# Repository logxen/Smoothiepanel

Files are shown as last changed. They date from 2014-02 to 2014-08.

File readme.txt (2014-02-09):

SmoothiePanel is an Open Source Hardware control interface for industrial robotic machinery. It adds a screen and user interface to allow easy control of a Smoothieboard. The current design brings a graphic LCD with RGB Backlight and changeable interface panel down to a port, optionally SPI, UART, or USB.

It is intended to control a Smoothieboard (http://smoothieware.org/), though could easily be connected to almost any logic control system. The firmware found in the firmware directory makes Smoothiepanel behave as a simple slave device that can be used via SPI, UART, or USB. As it is completely open source, however, it is very easy to write custom firmware that takes more advantage of its powerful 50MHz processor and 16 bits worth of extra gpio.

The latest version, Prototype 3, is based around the NXP LPC11UxxFBD64, which sports a 50MHz ARM Cortex-M0 processor with built in USB and up to 128KB of flash.

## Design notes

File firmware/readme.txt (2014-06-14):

Smoothiepanel is designed to function as a simple slave device. It can be used over USB, uart, and spi. USB and uart comms work the same, but spi is a bit different. The command list itself does not change between the three and can be found here: https://gist.github.com/logxen/8792351

USB and uart are set up for easy use from a keyboard. Each transaction consists of a command byte, represented by a decimal number from 0 to 255, followed by a space and a data byte, also represented by a decimal number from 0 to 255, followed by a '\n'. The panel will respond with a line containing two response bytes in hex format.

SPI uses the same two byte transactions. Drop the CS pin, send the command byte while receiving the previous command's first response byte, send the data byte while receiving the previous command's second response byte, then raise the CS pin. The CS pin must be raised between each 16-bit transaction to allow the panel to process the command.

To set up a build environment:

Clone https://github.com/arthurwolf/Smoothie and run the install script appropriate to your OS.

This will create a BuildShell script that you will run any time you want to use your GCC_ARM build environment.

Clone https://github.com/mbedmicro/mbed and get any basic dependencies that requires like Python installed.

Be sure to have run the BuildShell script, then from your mbed directory run: python workspace_tools/build.py -m LPC11U35_401 -t GCC_ARM -u

Finally, you need to add a section to your mbed/workspace_tools/tests.py like the following, but make sure to change "/path/to/git" to match wherever you cloned Smoothiepanel (for me that's "/home/logxen/git"):

    {
        "id": "Smoothiepanel", "description": "Smoothiepanel http://smoothieware.org/smoothiepanel",
        "source_dir": join("/path/to/git", "Smoothiepanel", "firmware"),
        "dependencies": [MBED_LIBRARIES, USB_LIBRARIES],
    },

To build:

Be sure to have run the BuildShell script, then from your mbed directory run: python workspace_tools/make.py -m LPC11U35_401 -t GCC_ARM -n Smoothiepanel

To flash:

If you are running Windows you can use the usb drag and drop system built into the mcu (plug in usb or reset while holding the isp button). Otherwise, for now, follow the process for flashing the Smoothie bootloader here using an FTDI without USB plugged in: http://smoothieware.org/flashing-the-bootloader

Eventually, I plan to have a bootloader with similar functionality to the one Triffid_Hunter wrote for Smoothie.

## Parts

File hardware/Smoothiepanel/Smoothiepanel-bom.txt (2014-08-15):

Partlist exported from C:/Users/Logxen/Documents/eagle/Smoothie/Smoothiepanel/Smoothiepanel/Smoothiepanel-Proto5.sch at 7/15/2014 9:03:24 AM

Qty Value         Device              Package            Parts                                                   Description                                                                                                                                                                                               MF MPN OC_FARNELL OC_NEWARK PROD_ID    VALUE
13  0.1uF         CAP0603-CAP         0603-CAP           C2, C3, C4, C5, C6, C7, C8, C9, C10, C12, C13, C16, C17 Capacitor                                                                                                                                                                                                                                             
6   0R            RESISTOR0603-RES    0603-RES           R6, R10, R11, R18, R20, R21                             Resistor                                                                                                                                                                                                                                              
1   1.5K          RESISTOR0603-RES    0603-RES           R23                                                     Resistor                                                                                                                                                                                                                                              
1   100R          RESISTOR0603-RES    0603-RES           R22                                                     Resistor                                                                                                                                                                                                                                              
8   10K           RESISTOR0603-RES    0603-RES           R2, R3, R4, R7, R8, R9, R13, R14                        Resistor                                                                                                                                                                                                                                              
1   10uF          CAP_POL1206         EIA3216            C11                                                     Capacitor Polarized                                                                                                                                                                                                                                   
1   12MHz         CRYSTALTHIN         CRYSTAL_3.2X2.5    Y1                                                      Crystals                                                                                                                                                                                                                                              
4   18pF          CAP0603-CAP         0603-CAP           C14, C15, C18, C19                                      Capacitor                                                                                                                                                                                                                                             
1   1uF           C-USC0805           C0805              C1                                                      CAPACITOR, American symbol                                                                                                                                                                                                                            
1   24K           RESISTOR0603-RES    0603-RES           R17                                                     Resistor                                                                                                                                                                                                                                              
2   330R          RESISTOR0603-RES    0603-RES           R1, R5                                                  Resistor                                                                                                                                                                                                                                              
2   33R           RESISTOR_0603MP     _0603MP            R16, R19                                                Resistors                                                                                                                                                                                                                                             
1   3K            RESISTOR0603-RES    0603-RES           R15                                                     Resistor                                                                                                                                                                                                                                              
1   BC857B        TRANSISTOR_PNPSMD   SOT23-3            Q1                                                      Generic PNP BJT. Double check pinouts against datasheets- not all devices are the same!                                                                                                                                                               
1   FB            INDUCTOR0603        0603               L1                                                      Inductors                                                                                                                                                                                                                                             
1   LM1117-3.3V   V_REG_LM1117SOT223  SOT223             U1                                                      Voltage Regulator LM1117                                                                                                                                                                                                                              
1   LPC176xFBD100 LPC1768             LQFP100            U2                                                      LPC1768 100 MHz 32-bit ARM Cortex-M3 based microcontroller featuring a high level of integration and low power consumption. 512 kB Flash, 64 kB SRAM, USB Device/Host/OTG, Ethernet, CAN, I2S, 10-bit DAC                                             
2   MBRA210LT3    DIODESMA            SMADIODE           D1, D2                                                  Diode                                                                                                                                                                                                                                                 
1   MCP4725       DAC_MCP4725         SOT23-6            U3                                                      MCP4725 - 12-Bit I2C DAC with on-board EEPROM                                                                                                                                                                                                         
1   POWER         LED0603             LED-0603           LED1                                                    LEDs                                                                                                                                                                                                                                                  
1   STATUS        LED0603             LED-0603           LED2                                                    LEDs                                                                                                                                                                                                                                                  

1   BOOT          TAC_SWITCHSMD       TACTILE_SWITCH_SMD S3                                                      Momentary Switch                                                                                                                                                                                                                                      
1   ISP           TAC_SWITCHSMD       TACTILE_SWITCH_SMD S2                                                      Momentary Switch                                                                                                                                                                                                                                      
1   JTAG          JTAG-CORTEXM3       2X05_1.27MM_SMT    JTAG1                                                   Serial Wire (SW-DP) Connector                                                                                                                                                                                                                         
1   RESET         TAC_SWITCHSMD       TACTILE_SWITCH_SMD S1                                                      Momentary Switch                                                                                                                                                                                                                                      
1   SD            SD_CARD_SOCKET4UCON SDCARD_4UCONN      X4                                                      SD Memory Card Connector, push-push normal type, CD enable, WP enable                                                                                                                                                                                 
1   SPI0          M03X2               2X3-SHROUDED       JP5                                                     Shrouded 2x3 .1" header, with keying.                                                                                                                                                                                                                 
1   USB-B         USBPTH              USB-B-PTH          X1                                                      USB Connectors                                                                                                                                                                                                                        CONN-08278 USB-B
1   VIN           180-2               180-2              Z1                                                      WEIDMUELLER CLAMP CONNECTOR                                                                                                                                                                                      unknown    unknown

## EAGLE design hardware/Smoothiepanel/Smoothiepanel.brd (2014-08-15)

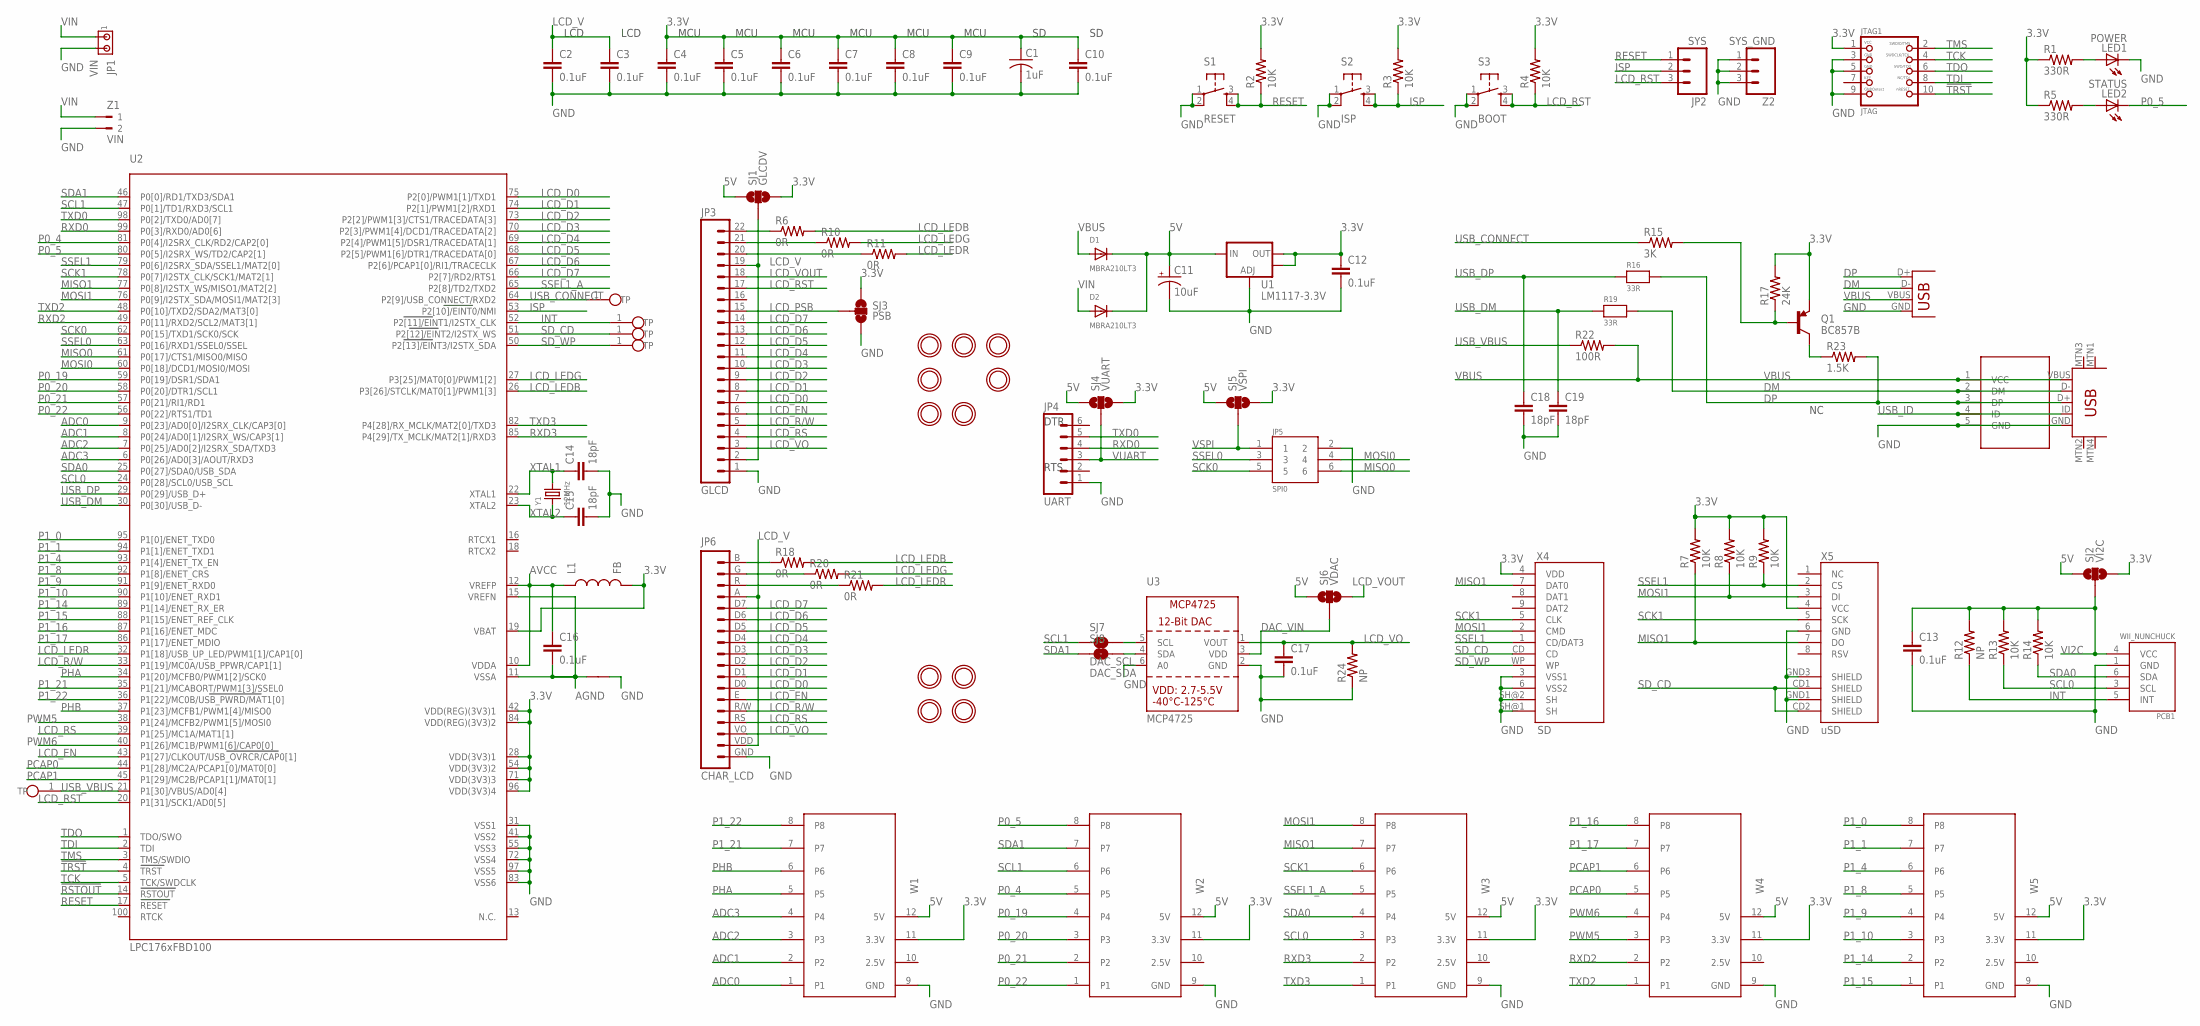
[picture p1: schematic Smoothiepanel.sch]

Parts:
C1: 1uF; C0805
C2, C3, C4, C5, C6, C7, C8, C9, C10, C12, C13, C16, C17: 0.1uF; 0603-CAP
C11: 10uF; EIA3216
C14, C15, C18, C19: 18pF; 0603-CAP
D1, D2: MBRA210LT3; SMADIODE
JP1: VIN; 10X02MTA
JP2: SYS; 1X03
JP3: GLCD; 1X22
JP4: UART; 1X06
JP5: SPI0; 2X3-SHROUDED
JP6: CHAR_LCD; TEXT_LCD
JTAG1: JTAG; 2X05_1.27MM_SMT
L1: FB; 0603
LED1: POWER; LED-0603
LED2: STATUS; LED-0603
MH1, MH2, MH3, MH4, MH5, MH6, MH7: MOUNTINGHOLE2.5_THICK; MOUNTINGHOLE_2.5_PLATED_THICK
MH8, MH9, MH10, MH11: MOUNTINGHOLE3.0THIN; MOUNTINGHOLE_3.0_PLATEDTHIN
N1: NET_LINK
PCB1: WII_NUNCHUCK
Q1: BC857B; SOT23-3
R1, R5: 330R; 0603-RES
R2, R3, R4, R7, R8, R9, R13, R14: 10K; 0603-RES
R6, R10, R11, R18, R20, R21: 0R; 0603-RES
R12, R24: NP; 0603-RES
R15: 3K; 0603-RES
R16, R19: 33R; _0603MP
R17: 24K; 0603-RES
R22: 100R; 0603-RES
R23: 1.5K; 0603-RES
S1: RESET; TACTILE_SWITCH_SMD
S2: ISP; TACTILE_SWITCH_SMD
S3: BOOT; TACTILE_SWITCH_SMD
SJ1: GLCDV; SJ_3
SJ2: VI2C; SJ_3
SJ3: PSB; SJ_3
SJ4: VUART; SJ_3
SJ5: VSPI; SJ_3
SJ6: VDAC; SJ_3
SJ7: DAC_SCL; SJ_2S-TRACE
SJ8: DAC_SDA; SJ_2S-TRACE
TP1, TP3, TP4, TP5, TP6: TPAD1.5; TPAD-1.5
U1: LM1117-3.3V; SOT223
U2: LPC176xFBD100; LQFP100
U3: MCP4725; SOT23-6
W1: WING1; PAPILIO-WING-8BITS-F
W2: WING2; PAPILIO-WING-8BITS-F
W3: WING3; PAPILIO-WING-8BITS-F
W4: WING4; PAPILIO-WING-8BITS-F
W5: WING5; PAPILIO-WING-8BITS-F
X1: USB-B; USB-B-PTH
X2: mUSB; USB-MINIB
X3: USB-MICROB-SMDRECEPT; USB-MICROB-RECEPT
X4: SD; SDCARD_4UCONN
X5: uSD; MICRO-SD-SOCKET-PP
Y1: 12MHz; CRYSTAL_3.2X2.5
Z1: VIN; 180-2
Z2: SYS_GND; 1X03

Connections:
3.3V: C1.1, C4.1, C5.1, C6.1, C7.1, C8.1, C9.1, C10.1, C12.1, JTAG1.1, L1.2, Q1.2 (E), R1.1, R2.2, R3.2, R4.2, R5.1, R7.2, R8.2, R9.2, R17.2, SJ1.3, SJ2.3, SJ3.1, SJ4.3, SJ5.3, U1.2 (OUT), U1.4 (OUT), U2.19 (VBAT), U2.28 (VDD(3V3)1), U2.42 (VDD(REG)(3V3)1), U2.54 (VDD(3V3)2), U2.71 (VDD(3V3)3), U2.84 (VDD(REG)(3V3)2), U2.96 (VDD(3V3)4), W1.11 (3.3V), W2.11 (3.3V), W3.11 (3.3V), W4.11 (3.3V), W5.11 (3.3V), X4.4 (VDD), X5.4 (VCC)
5V: C11.A (+), D1.C, D2.C, SJ1.1, SJ2.1, SJ4.1, SJ5.1, SJ6.1, U1.3 (IN), W1.12 (5V), W2.12 (5V), W3.12 (5V), W4.12 (5V), W5.12 (5V)
!RSTOUT!: U2.14 (RSTOUT)
!TRST!: JTAG1.10, U2.4 (TRST)
ADC0: U2.9 (P0[23]/AD0[0]/I2SRX_CLK/CAP3[0]), W1.1
ADC1: U2.8 (P0[24]/AD0[1]/I2SRX_WS/CAP3[1]), W1.2
ADC2: U2.7 (P0[25]/AD0[2]/I2SRX_SDA/TXD3), W1.3
ADC3: U2.6 (P0[26]/AD0[3]/AOUT/RXD3), W1.4
AGND: C16.2, N1.P$1, U2.11 (VSSA), U2.15 (VREFN)
AVCC: C16.1, L1.1, U2.10 (VDDA), U2.12 (VREFP)
DAC_SCL_RES: SJ7.2, U3.5 (SCL)
DAC_SDA_RES: SJ8.2, U3.4 (SDA)
DAC_VIN: SJ6.2, U3.3 (VDD)
DM: R19.2, X1.D-, X2.D-, X3.2 (DM)
DP: R16.2, R23.2, X1.D+, X2.D+, X3.3 (DP)
GND: C1.2, C2.2, C3.2, C4.2, C5.2, C6.2, C7.2, C8.2, C9.2, C10.2, C11.C (-), C12.2, C13.2, C14.2, C15.2, C17.2, C18.2, C19.2, JP1.2, JP3.1, JP4.1, JP5.2, JP6.GND (1), JTAG1.3, JTAG1.5, JTAG1.9, LED1.C, N1.P$2, PCB1.1 (GND), R24.1, S1.1, S1.2, S2.1, S2.2, S3.1, S3.2, SJ3.3, U1.1 (ADJ), U2.31 (VSS1), U2.41 (VSS2), U2.55 (VSS3), U2.72 (VSS4), U2.83 (VSS6), U2.97 (VSS5), U3.2 (GND), U3.6 (A0), W1.9 (GND), W2.9 (GND), W3.9 (GND), W4.9 (GND), W5.9 (GND), X1.GND, X2.GND, X3.5 (GND), X4.3 (VSS1), X4.6 (VSS2), X4.SH@1 (SH), X4.SH@2 (SH), X5.6 (GND), X5.GND1 (SHIELD), X5.GND3 (SHIELD), Z1.2, Z2.1, Z2.2, Z2.3
INT: PCB1.5 (INT), R12.1, TP4.1, U2.52 (P2[11]/EINT1/I2STX_CLK)
ISP: JP2.2, R3.1, S2.3, S2.4, U2.53 (P2[10]/EINT0/NMI)
LCD_D0: JP3.7, JP6.D0 (7), U2.75 (P2[0]/PWM1[1]/TXD1)
LCD_D1: JP3.8, JP6.D1 (8), U2.74 (P2[1]/PWM1[2]/RXD1)
LCD_D2: JP3.9, JP6.D2 (9), U2.73 (P2[2]/PWM1[3]/CTS1/TRACEDATA[3])
LCD_D3: JP3.10, JP6.D3 (10), U2.70 (P2[3]/PWM1[4]/DCD1/TRACEDATA[2])
LCD_D4: JP3.11, JP6.D4 (11), U2.69 (P2[4]/PWM1[5]/DSR1/TRACEDATA[1])
LCD_D5: JP3.12, JP6.D5 (12), U2.68 (P2[5]/PWM1[6]/DTR1/TRACEDATA[0])
LCD_D6: JP3.13, JP6.D6 (13), U2.67 (P2[6]/PCAP1[0]/RI1/TRACECLK)
LCD_D7: JP3.14, JP6.D7 (14), U2.66 (P2[7]/RD2/RTS1)
LCD_EN: JP3.6, JP6.E (6), U2.43 (P1[27]/CLKOUT/USB_OVRCR/CAP0[1])
LCD_LEDB: R6.2, R18.2, U2.26 (P3[26]/STCLK/MAT0[1]/PWM1[3])
LCD_LEDB_RES: JP3.22, R6.1
LCD_LEDB_RES1: JP6.B (18), R18.1
LCD_LEDG: R10.2, R20.2, U2.27 (P3[25]/MAT0[0]/PWM1[2])
LCD_LEDG_RES: JP3.21, R10.1
LCD_LEDG_RES1: JP6.G (17), R20.1
LCD_LEDR: R11.2, R21.2, U2.32 (P1[18]/USB_UP_LED/PWM1[1]/CAP1[0])
LCD_LEDR_RES: JP3.20, R11.1
LCD_LEDR_RES1: JP6.R (16), R21.1
LCD_PSB: JP3.15, SJ3.2
LCD_R/W: JP3.5, JP6.R/W (5), U2.33 (P1[19]/MC0A/USB_PPWR/CAP1[1])
LCD_RS: JP3.4, JP6.RS (4), U2.39 (P1[25]/MC1A/MAT1[1])
LCD_RST: JP2.3, JP3.17, R4.1, S3.3, S3.4, U2.20 (P1[31]/SCK1/AD0[5])
LCD_V: C2.1, C3.1, JP3.2, JP3.19, JP6.A (15), JP6.VDD (2), SJ1.2
LCD_VO: C17.1, JP3.3, JP6.VO (3), R24.2, U3.1 (VOUT)
LCD_VOUT: JP3.18, SJ6.3
LED1_R: LED1.A, R1.2
LED2_R: LED2.A, R5.2
MISO0: JP5.6, U2.61 (P0[17]/CTS1/MISO0/MISO)
MISO1: R7.1, U2.77 (P0[8]/I2STX_WS/MISO1/MAT2[2]), W3.7, X4.7 (DAT0), X5.7 (DO)
MOSI0: JP5.4, U2.60 (P0[18]/DCD1/MOSI0/MOSI)
MOSI1: R8.1, U2.76 (P0[9]/I2STX_SDA/MOSI1/MAT2[3]), W3.8, X4.2 (CMD), X5.3 (DI)
P0_4: U2.81 (P0[4]/I2SRX_CLK/RD2/CAP2[0]), W2.5
P0_5: LED2.C, U2.80 (P0[5]/I2SRX_WS/TD2/CAP2[1]), W2.8
P0_19: U2.59 (P0[19]/DSR1/SDA1), W2.4
P0_20: U2.58 (P0[20]/DTR1/SCL1), W2.3
P0_21: U2.57 (P0[21]/RI1/RD1), W2.2
P0_22: U2.56 (P0[22]/RTS1/TD1), W2.1
P1_0: U2.95 (P1[0]/ENET_TXD0), W5.8
P1_1: U2.94 (P1[1]/ENET_TXD1), W5.7
P1_4: U2.93 (P1[4]/ENET_TX_EN), W5.6
P1_8: U2.92 (P1[8]/ENET_CRS), W5.5
P1_9: U2.91 (P1[9]/ENET_RXD0), W5.4
P1_10: U2.90 (P1[10]/ENET_RXD1), W5.3
P1_14: U2.89 (P1[14]/ENET_RX_ER), W5.2
P1_15: U2.88 (P1[15]/ENET_REF_CLK), W5.1
P1_16: U2.87 (P1[16]/ENET_MDC), W4.8
P1_17: U2.86 (P1[17]/ENET_MDIO), W4.7
P1_21: U2.35 (P1[21]/MCABORT/PWM1[3]/SSEL0), W1.7
P1_22: U2.36 (P1[22]/MC0B/USB_PWRD/MAT1[0]), W1.8
PCAP0: U2.44 (P1[28]/MC2A/PCAP1[0]/MAT0[0]), W4.5
PCAP1: U2.45 (P1[29]/MC2B/PCAP1[1]/MAT0[1]), W4.6
PHA: U2.34 (P1[20]/MCFB0/PWM1[2]/SCK0), W1.5
PHB: U2.37 (P1[23]/MCFB1/PWM1[4]/MISO0), W1.6
PWM5: U2.38 (P1[24]/MCFB2/PWM1[5]/MOSI0), W4.3
PWM6: U2.40 (P1[26]/MC1B/PWM1[6]/CAP0[0]), W4.4
RESET: JP2.1, R2.1, S1.3, S1.4, U2.17 (RESET)
RXD0: JP4.4, U2.99 (P0[3]/RXD0/AD0[6])
RXD2: U2.49 (P0[11]/RXD2/SCL2/MAT3[1]), W4.2
RXD3: U2.85 (P4[29]/TX_MCLK/MAT2[1]/RXD3), W3.2
SCK0: JP5.5, U2.62 (P0[15]/TXD1/SCK0/SCK)
SCK1: U2.78 (P0[7]/I2STX_CLK/SCK1/MAT2[1]), W3.6, X4.5 (CLK), X5.5 (SCK)
SCL0: PCB1.3 (SCL), R13.1, U2.24 (P0[28]/SCL0/USB_SCL), W3.3
SCL1: SJ7.1, U2.47 (P0[1]/TD1/RXD3/SCL1), W2.6
SDA0: PCB1.6 (SDA), R14.1, U2.25 (P0[27]/SDA0/USB_SDA), W3.4
SDA1: SJ8.1, U2.46 (P0[0]/RD1/TXD3/SDA1), W2.7
SD_CD: TP5.1, U2.51 (P2[12]/EINT2/I2STX_WS), X4.CD, X5.CD1 (SHIELD), X5.CD2 (SHIELD)
SD_WP: TP6.1, U2.50 (P2[13]/EINT3/I2STX_SDA), X4.WP
SSEL0: JP5.3, U2.63 (P0[16]/RXD1/SSEL0/SSEL)
SSEL1: R9.1, U2.79 (P0[6]/I2SRX_SDA/SSEL1/MAT2[0]), X4.1 (CD/DAT3), X5.2 (CS)
SSEL1_A: U2.65 (P2[8]/TD2/TXD2), W3.5
TCK: JTAG1.4, U2.5 (TCK/SWDCLK)
TDI: JTAG1.8, U2.2 (TDI)
TDO: JTAG1.6, U2.1 (TDO/SWO)
TMS: JTAG1.2, U2.3 (TMS/SWDIO)
TXD0: JP4.5, U2.98 (P0[2]/TXD0/AD0[7])
TXD2: U2.48 (P0[10]/TXD2/SDA2/MAT3[0]), W4.1
TXD3: U2.82 (P4[28]/RX_MCLK/MAT2[0]/TXD3), W3.1
USB_CONNECT: R15.1, TP3.1, U2.64 (P2[9]/USB_CONNECT/RXD2)
USB_CONNECT_BASE: Q1.1 (B), R15.2, R17.1
USB_CONNECT_COLLECTOR: Q1.3 (C), R23.1
USB_DM: C19.1, R19.1, U2.30 (P0[30]/USB_D-)
USB_DP: C18.1, R16.1, U2.29 (P0[29]/USB_D+)
USB_ID: X2.ID, X3.4 (ID)
USB_VBUS: R22.1, TP1.1, U2.21 (P1[30]/VBUS/AD0[4])
VBUS: D1.A, R22.2, X1.VBUS, X2.VBUS, X3.1 (VCC)
VI2C: C13.1, PCB1.4 (VCC), R12.2, R13.2, R14.2, SJ2.2
VIN: D2.A, JP1.1, Z1.1
VSPI: JP5.1, SJ5.2
VUART: JP4.3, SJ4.2
XTAL1: C14.1, U2.22 (XTAL1), Y1.2
XTAL2: C15.1, U2.23 (XTAL2), Y1.1

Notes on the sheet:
DTR
RTS
LCD
MCU

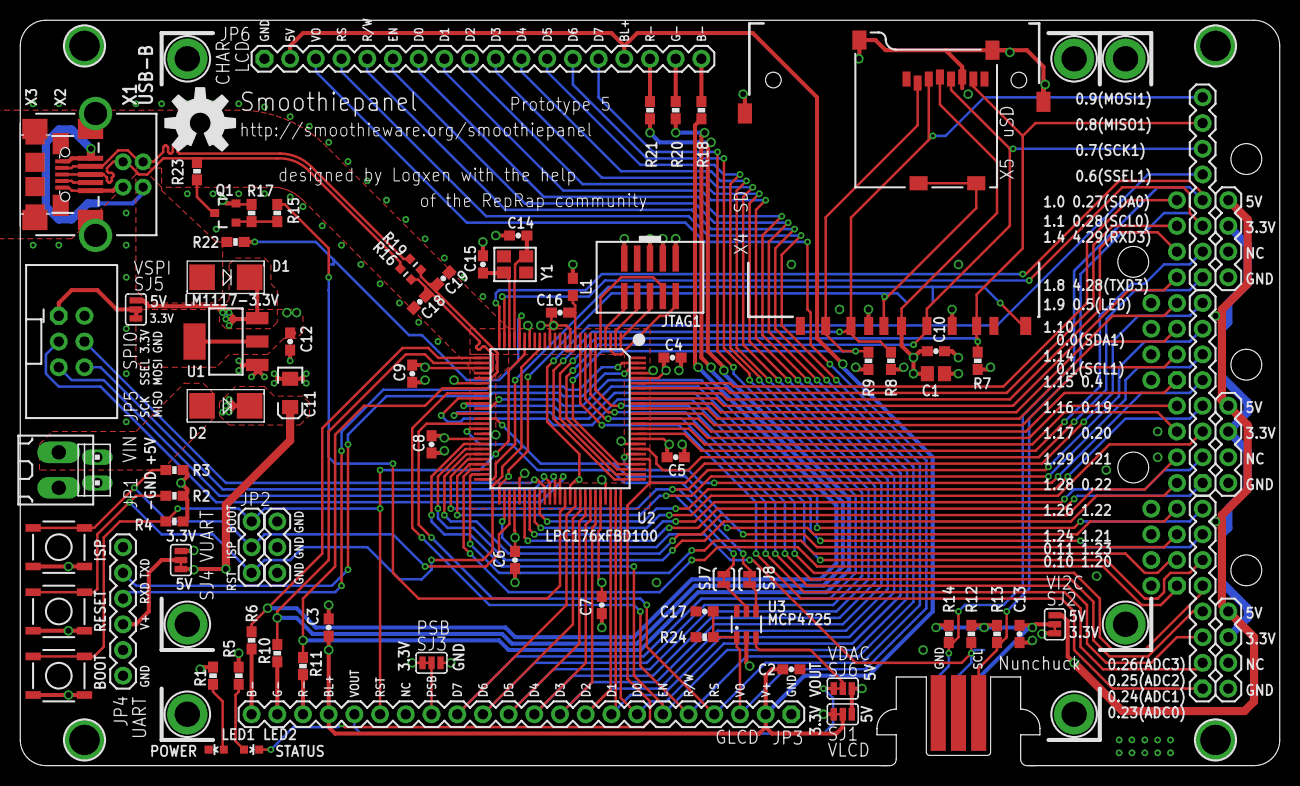
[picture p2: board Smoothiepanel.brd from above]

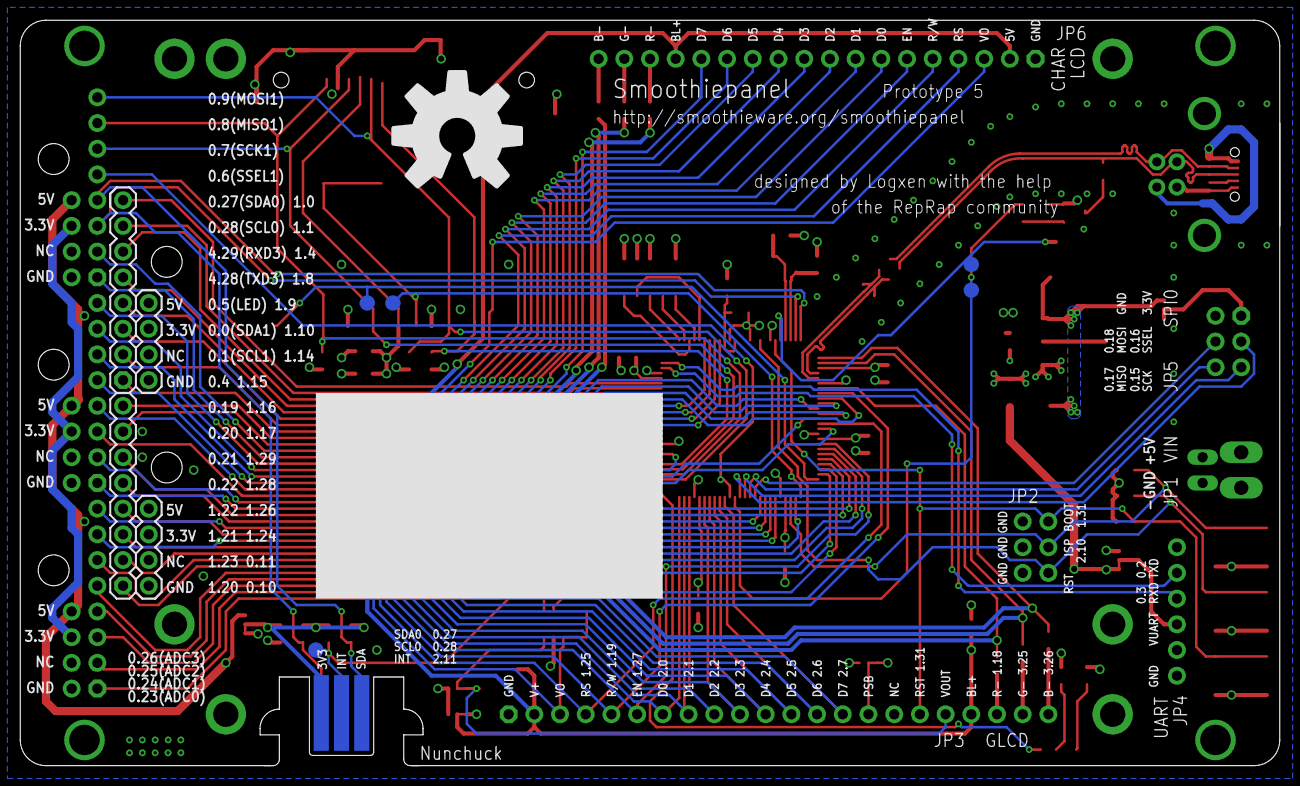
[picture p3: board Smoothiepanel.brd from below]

Board: 4 copper layers, 124.5 x 73.7 mm, 103 parts (8 on the bottom side), 108 nets.

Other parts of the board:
U$1: OSHW-LOGO-HUGE
U$2: OSHW-LOGO-L

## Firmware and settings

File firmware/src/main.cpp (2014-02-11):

#include "mbed.h"
#include "USBSerial.h"

#include "nunchuck.h"
#include "utils.h"

#define USB_VID         0x1D50
#define USB_PID         0x60A0
#define USB_REV         0x00
#define VERSION         0x0001

USBSerial usbdevice(USB_VID, USB_PID, USB_REV); // vid pid rev
Serial uart(P0_19, P0_18); // tx, rx
SPISlave spidevice(P0_9, P0_8, P0_10, P0_2); // mosi, miso, sck, ssel

BusInOut lcd_d(P1_0, P1_1, P1_2, P1_3, P1_4, P1_5, P1_6, P1_7);
DigitalOut lcd_rs(P0_17);
DigitalOut lcd_rw(P0_10);
DigitalOut lcd_en(P0_20);
DigitalOut lcd_psb(P1_28);
DigitalOut lcd_rst(P1_27);

SPI spimaster(P1_22, P1_21, P1_20); // mosi, miso, sck
DigitalOut spi_ssel(P1_23); // spi port ssel
DigitalOut sd_ssel(P0_7); // sd card ssel
DigitalIn sd_cd(P1_18); // sd card detect
DigitalIn sd_wp(P1_19); // sd card write protect

I2C i2c(P0_5, P0_4); // sda, scl

int nunchuck_rate;

bool encoder_running = false;
int16_t encoder_count = 0;
uint8_t encoder_a_pin;
uint8_t encoder_b_pin;
bool encoder_a_wing;
bool encoder_b_wing;

int processcommand(int c, int d) {
    int r;
    uint32_t t;
//    analogin_t adc;

    switch (c) {
        // System
        case 0x00: // nop
            r = 0x0000;
            break;

        case 0x01: // read usb vid
            r = USB_VID;
            break;
        case 0x02: // read usb pid
            r = USB_PID;
            break;
        case 0x03: // read usb revision
            r = USB_REV;
            break;
        case 0x04: // read version
            r = VERSION;
            break;

        // LCD
        case 0x10: // write lcd data byte
            lcd_d.output();
            lcd_d = d;
            lcd_rs = 1; // 0 cmd, 1 dat
            lcd_rw = 0; // 0 write, 1 read
            lcd_en = 0;
            wait(0.01);
            lcd_en = 1;
            wait(0.01);
            lcd_en = 0;
            r = 0x1000 + d;
            break;
        case 0x11: // read lcd data byte
            lcd_d.input();
            lcd_rs = 1; // 0 cmd, 1 dat
            lcd_rw = 1; // 0 write, 1 read
            lcd_en = 0;
            wait(0.01);
            lcd_en = 1;
            wait(0.01);
            r = 0x1100 + lcd_d;
            lcd_en = 0;
            break;
        case 0x12: // write lcd command byte
            lcd_d.output();
            lcd_d = d;
            lcd_rs = 0; // 0 cmd, 1 dat
            lcd_rw = 0; // 0 write, 1 read
            lcd_en = 0;
            wait(0.01);
            lcd_en = 1;
            wait(0.01);
            lcd_en = 0;
            r = 0x1200 + d;
            break;
        case 0x13: // read lcd command byte
            lcd_d.input();
            lcd_rs = 0; // 0 cmd, 1 dat
            lcd_rw = 1; // 0 write, 1 read
            lcd_en = 0;
            wait(0.01);
            lcd_en = 1;
            wait(0.01);
            r = 0x1300 + lcd_d;
            lcd_en = 0;
            break;
        case 0x14: // reset lcd
            lcd_rst = 1;
            wait(0.01);
            lcd_rst = 0;
            r = 0x1400 + d;
            break;

        // LCD Contrast
        case 0x18: // write lcd contrast dac
            r = 0x1800 + d;
            break;
        case 0x19: // read lcd contrast dac
            r = 0x1900 + d;
            break;

        // I2C
        case 0x20: // write i2c
            r = 0x2000 + i2c.write(d);
            break;
        case 0x21: // read i2c
            r = 0x2100 + i2c.read(d);
            break;
        case 0x22: // start i2c + address
            i2c.start();
            r = 0x2200 + i2c.write(d);
            break;
        case 0x23: // stop i2c
            i2c.stop();
            r = 0x2300;
            break;

        // SPI
        case 0x28: // write spi
            r = 0x2800 + spimaster.write(d);

        // Wing1
        case 0x40: // write wing1
            t = LPC_GPIO->PIN[0];
            t &= 0xFF3E07FF;
            t |= (d & 0x3F) << 11;
            t |= (d & 0xC0) << 16;
            LPC_GPIO->PIN[0] = t;
            r = 0x4000 + d;
            break;
        case 0x41: // read wing1
            t = LPC_GPIO->PIN[0];
            r = 0x4100 + ((t & 0x0001F800) >> 11) + ((t & 0x00C00000) >> 16);
            break;
        case 0x42: // set wing1
            LPC_GPIO->SET[0] = ((d & 0x3F) << 11) + ((d & 0xC0) << 16);
            r = 0x4200 + d;
            break;
        case 0x43: // clear wing1
            LPC_GPIO->CLR[0] = ((d & 0x3F) << 11) + ((d & 0xC0) << 16);
            r = 0x4300 + d;
            break;
        case 0x44: // not wing1
            LPC_GPIO->NOT[0] = ((d & 0x3F) << 11) + ((d & 0xC0) << 16);
            r = 0x4400 + d;
            break;
        case 0x45: // dir wing1
            t = LPC_GPIO->DIR[0];
            t &= 0xFF3E07FF;
            t |= (d & 0x3F) << 11;
            t |= (d & 0xC0) << 16;
            LPC_GPIO->DIR[0] = t;
            r = 0x4500 + d;
            break;
        case 0x46: // masked write wing1
            r = 0x4600 + d;
            break;
        case 0x47: // mask wing1
            r = 0x4700 + d;
            break;
        case 0x48: // configure wing1 bit0 P0_11
            r = write_iocon(P0_11, d);
            break;
        case 0x49: // configure wing1 bit1 P0_12
            r = write_iocon(P0_12, d);
            break;
        case 0x4A: // configure wing1 bit2 P0_13
            r = write_iocon(P0_13, d);
            break;
        case 0x4B: // configure wing1 bit3 P0_14
            r = write_iocon(P0_14, d);
            break;
        case 0x4C: // configure wing1 bit4 P0_15
            r = write_iocon(P0_15, d);
            break;
        case 0x4D: // configure wing1 bit5 P0_16
            r = write_iocon(P0_16, d);
            break;
        case 0x4E: // configure wing1 bit6 P0_22
            r = write_iocon(P0_22, d);
            break;
        case 0x4F: // configure wing1 bit7 P0_23
            r = write_iocon(P0_23, d);
            break;

        // Wing2
        case 0x50: // write wing2
            t = LPC_GPIO->PIN[1];
            t &= 0xFFFF00FF;
            t |= (d & 0xFF) << 8;
            LPC_GPIO->PIN[1] = t;
            r = 0x5000 + d;
            break;
        case 0x51: // read wing2
            r = 0x5100 + ((LPC_GPIO->PIN[1] & 0x0000FF00) >> 8);
            break;
        case 0x52: // set wing2
            LPC_GPIO->SET[1] = (d & 0xFF) << 8;
            r = 0x5200 + d;
            break;
        case 0x53: // clear wing2
            LPC_GPIO->CLR[1] = (d & 0xFF) << 8;
            r = 0x5300 + d;
            break;
        case 0x54: // not wing2
            LPC_GPIO->NOT[1] = (d & 0xFF) << 8;
            r = 0x5400 + d;
            break;
        case 0x55: // dir wing2
            t = LPC_GPIO->DIR[1];
            t &= 0xFFFF00FF;
            t |= (d & 0xFF) << 8;
            LPC_GPIO->DIR[1] = t;
            r = 0x5500 + d;
            break;
        case 0x56: // masked write wing2
            r = 0x5600 + d;
            break;
        case 0x57: // mask wing2
            r = 0x5700 + d;
            break;
        case 0x58: // configure wing2 bit0 P1_8
            r = write_iocon(P1_8, d);
            break;
        case 0x59: // configure wing2 bit1 P1_9
            r = write_iocon(P1_9, d);
            break;
        case 0x5A: // configure wing2 bit2 P1_10
            r = write_iocon(P1_10, d);
            break;
        case 0x5B: // configure wing2 bit3 P1_11
            r = write_iocon(P1_11, d);
            break;
        case 0x5C: // configure wing2 bit4 P1_12
            r = write_iocon(P1_12, d);
            break;
        case 0x5D: // configure wing2 bit5 P1_13
            r = write_iocon(P1_13, d);
            break;
        case 0x5E: // configure wing2 bit6 P1_14
            r = write_iocon(P1_14, d);
            break;
        case 0x5F: // configure wing2 bit7 P1_15
            r = write_iocon(P1_15, d);
            break;

        // Ext Pins
        case 0x60: // write ext
            LPC_GPIO->W0[1] = d & 0x80;
            LPC_GPIO->W0[7] = d & 0x10;
            LPC_GPIO->W0[21] = d & 0x40;
            LPC_GPIO->W1[23] = d & 0x20;
            t = LPC_GPIO->PIN[1];
            t &= 0xFFF0FFFF;
            t |= (d & 0x0F) << 16;
            LPC_GPIO->PIN[1] = t;
            r = 0x6000 + d;
            break;
        case 0x61: // read ext
            t = LPC_GPIO->B0[1] << 7;
            t |= LPC_GPIO->B0[7] << 4;
            t |= LPC_GPIO->B0[21] << 6;
            t |= LPC_GPIO->B1[23] << 5;
            t |= (LPC_GPIO->PIN[1] & 0x000F0000) >> 16;
            r = 0x6100 + t;
            break;
        case 0x62: // set ext
            t = (d & 0x80) >> 6;
            t |= (d & 0x10) << 3;
            t |= (d & 0x40) << 15;
            LPC_GPIO->SET[0] = t;
            t = (d & 0x0F) << 16;
            t |= (d & 0x20) << 18;
            LPC_GPIO->SET[1] = t;
            r = 0x6200 + d;
            break;
        case 0x63: // clear ext
            t = (d & 0x80) >> 6;
            t |= (d & 0x10) << 3;
            t |= (d & 0x40) << 15;
            LPC_GPIO->CLR[0] = t;
            t = (d & 0x0F) << 16;
            t |= (d & 0x20) << 18;
            LPC_GPIO->CLR[1] = t;
            r = 0x6300 + d;
            break;
        case 0x64: // not ext
            t = (d & 0x80) >> 6;
            t |= (d & 0x10) << 3;
            t |= (d & 0x40) << 15;
            LPC_GPIO->NOT[0] = t;
            t = (d & 0x0F) << 16;
            t |= (d & 0x20) << 18;
            LPC_GPIO->NOT[1] = t;
            r = 0x6400 + d;
            break;
        case 0x65: // dir ext
            t = LPC_GPIO->DIR[0] & 0xFFDFFF7D;
            t |= (d & 0x80) >> 6;
            t |= (d & 0x10) << 3;
            t |= (d & 0x40) << 15;
            LPC_GPIO->DIR[0] = t;
            t = LPC_GPIO->DIR[1] & 0xFF70FFFF;
            t |= (d & 0x0F) << 16;
            t |= (d & 0x20) << 18;
            LPC_GPIO->DIR[1] = t;
            r = 0x6500 + d;
            break;
        case 0x66: // masked write ext
            r = 0x6600 + d;
            break;
        case 0x67: // mask ext
            r = 0x6700 + d;
            break;
        case 0x6C: // configure ext bit4 P1_16 DAC_SDA
            r = write_iocon(P1_16, d);
            break;
        case 0x6D: // configure ext bit5 P1_17 DAC_SCL
            r = write_iocon(P1_17, d);
            break;
        case 0x69: // configure ext bit1 P1_18 SD_CD
            r = write_iocon(P1_18, d);
            break;
        case 0x6A: // configure ext bit2 P1_19 SD_WP
            r = write_iocon(P1_19, d);
            break;
        case 0x68: // configure ext bit0 P0_7  SD_SSEL
            r = write_iocon(P0_7, d);
            break;
        case 0x6B: // configure ext bit3 P1_23 SPI_SSEL
            r = write_iocon(P1_23, d);
            break;
        case 0x6E: // configure ext bit6 P0_21 I2C_INT
            r = write_iocon(P0_21, d);
            break;
        case 0x6F: // configure ext bit7 P0_1  ISP
            r = write_iocon(P0_1, d);
            break;

        // ADC (available on Wing1 pins by setting 0x48 - 0x4F bits 2:0 to 0x2)
        case 0x70: // sample + read adc0
            r = read_adc(P0_11);
            break;
        case 0x71: // sample + read adc0
            r = read_adc(P0_12);
            break;
        case 0x72: // sample + read adc0
            r = read_adc(P0_13);
            break;
        case 0x73: // sample + read adc0
            r = read_adc(P0_14);
            break;
        case 0x74: // sample + read adc0
            r = read_adc(P0_15);
            break;
        case 0x75: // sample + read adc0
            r = read_adc(P0_16);
            break;
        case 0x76: // sample + read adc0
            r = read_adc(P0_22);
            break;
        case 0x77: // sample + read adc0
            r = read_adc(P0_23);
            break;

        // PWM (available on pins: W2_5 W2_6 W2_7 W1_6 LCD_R LCD_G LCD_B)
        case 0x78: // write pwm control reg
            r = 0x7800 + pwm_init(d);
            break;
        case 0x79: // write pwm1 / W2_5 / P1_13
            r = 0x7900 + pwm_write(0, d);
            break;
        case 0x7A: // write pwm2 / W2_6 / P1_14
            r = 0x7A00 + pwm_write(1, d);
            break;
        case 0x7B: // write pwm3 / W2_7 / P1_15
            r = 0x7B00 + pwm_write(2, d);
            break;
        case 0x7C: // write pwm5 / W1_6 / P0_22
            r = 0x7C00 + pwm_write(3, d);
            break;
        case 0x7D: // write pwm6 / LCD_R / P1_24
            r = 0x7D00 + pwm_write(4, d);
            break;
        case 0x7E: // write pwm7 / LCD_G / P1_25
            r = 0x7E00 + pwm_write(5, d);
            break;
        case 0x7F: // write pwm8 / LCD_B / P1_26
            r = 0x7F00 + pwm_write(6, d);
            break;

        // other functions

        // nunchuck
        case 0x80: // init nunchuck (write 0 to sample manually, write >0 to set auto sampling speed)
            nunchuck_poll(&i2c);
            nunchuck_rate = (nunchuck_type >= 0) ? d : 0;
            r = nunchuck_type;
            break;
        case 0x81: // read nunchuck device type
            r = nunchuck_type;
            break;
        case 0x82: // read nunchuck byte 1 & 2
            r = (nunchuck_data[0] << 8) + nunchuck_data[1];
            break;
        case 0x83: // read nunchuck byte 3 & 4
            r = (nunchuck_data[2] << 8) + nunchuck_data[3];
            break;
        case 0x84: // read nunchuck byte 5 & 6
            r = (nunchuck_data[4] << 8) + nunchuck_data[5];
            break;
        case 0x85: // sample nunchuck
            r = 0x8500 + nunchuck_read(&i2c);
            break;

        // encoder
        case 0x86: // init encoder (data bits: 7 channel a wing, 6:4 channel a pin, 3 channel b wing, 2:0 channel b pin)
            r = 0x8600;
            encoder_a_wing = (d>>7)&0x01;
            encoder_a_pin = (d>>4)&0x07;
            encoder_b_wing = (d>>3)&0x01;
            encoder_b_pin = d&0x07;
            encoder_running = true;
            break;
        case 0x87: // read encoder (data: 1 to reset counter, 0 to not reset counter)
            r = encoder_count;
            if (d == 1) encoder_count = 0;
            break;

        // 0xDEAD
        default: // unrecognized command
            r = 0xDEAD;
            break;
    }
    return r;
}

char usb_buf[16];
int usb_pos = 0;
void usbdevice_onloop() {
    if(usbdevice.available()) {
        usb_buf[usb_pos] = usbdevice.getc();
        if (usb_buf[usb_pos] == '\n') {
            usb_buf[usb_pos] = '\0';
            usb_pos = 0;
            char * command = strtok(usb_buf, " \t\r\n");
            char * data = strtok(NULL, " \t\r\n");
            if(command != NULL && data != NULL) {
                int c = atoi(command);
                int d = atoi(data);
                int r = processcommand(c, d);
                usbdevice.printf("%d %d\r\n", c, d);
                usbdevice.printf("0x%x 0x%x\r\n", (r & 0xFF00) >> 8, r & 0x00FF);
            }
        }
        else if (usb_pos < 15) {
            usb_pos++;
        }
    }
}

char uart_buf[16];
int uart_pos = 0;
void uartdevice_onloop() {
    if(uart.readable()) {
        uart_buf[uart_pos] = uart.getc();
        if(uart_buf[uart_pos] == '\n') {
            uart_buf[uart_pos] = '\0';
            uart_pos = 0;
            char * command = strtok(uart_buf, " \t\r\n");
            char * data = strtok(NULL, " \t\r\n");
            if(command != NULL && data != NULL) {
                int c = atoi(command);
                int d = atoi(data);
                int r = processcommand(c, d);
                uart.printf("%d %d\r\n", c, d);
                uart.printf("0x%x 0x%x\r\n", (r & 0xFF00) >> 8, r & 0x00FF);
//                    uart.putc((r & 0xFF00) >> 8);
//                    uart.putc(r & 0x00FF);
            }
        }
        else if(uart_pos < 15) {
            uart_pos++;
        }
    }
}

void spidevice_onloop() {
    if(spidevice.receive()) {
        int s = spidevice.read();
        int c = (s & 0xFF00) >> 8;
        int d = s & 0x00FF;
        int r = processcommand(c, d);
        spidevice.reply(r);
    }
}

void nunchuck_onloop() {
    if(nunchuck_rate > 0) {
        if(LPC_GPIO->B0[21]) {
            if(nunchuck_state < 10) {
                nunchuck_reset();
                nunchuck_state++;
            }
            else if(nunchuck_state == 10) {
                nunchuck_poll(&i2c);
                if(nunchuck_type >= 0) {
                    nunchuck_state = 11;
                }
            }
            else if(nunchuck_state < (nunchuck_rate*1000)) {
                nunchuck_state++;
            }
            else {
                nunchuck_state = 11;
                nunchuck_read(&i2c);
                //uart.printf("polling nunchuck... %x %x %x %x %x %x\r\n", nunchuck_data[0], nunchuck_data[1], nunchuck_data[2], nunchuck_data[3], nunchuck_data[4], nunchuck_data[5]);
            }
        }
        else {
            nunchuck_reset();
            nunchuck_state = 0;
        }
    }
}

void encoder_onloop() {
	static int8_t enc_states[] = {0,-1,1,0,1,0,0,-1,-1,0,0,1,0,1,-1,0};
	static uint8_t old_AB = 0;
    if(encoder_running) {
	    old_AB <<= 2;                   //remember previous state
        old_AB |= (processcommand(encoder_a_wing == 0 ? 0x41 : 0x51, 0x00)>>encoder_a_pin)&0x01;
        old_AB |= ((processcommand(encoder_b_wing == 0 ? 0x41 : 0x51, 0x00)>>encoder_b_pin)&0x01)<<1;
        encoder_count += enc_states[(old_AB&0x0f)];
    }
}

void init_gpio() {
    LPC_IOCON->TDI_PIO0_11 = 0x81;
    LPC_IOCON->TMS_PIO0_12 = 0x81;
    LPC_IOCON->TDO_PIO0_13 = 0x81;
    LPC_IOCON->TRST_PIO0_14 = 0x81;
    LPC_IOCON->SWDIO_PIO0_15 = 0x81;
    LPC_IOCON->PIO0_16 = 0x80;
    LPC_IOCON->PIO0_22 = 0x80;
    LPC_IOCON->PIO0_23 = 0x80;

    LPC_IOCON->PIO1_8 = 0x80;
    LPC_IOCON->PIO1_9 = 0x80;
    LPC_IOCON->PIO1_10 = 0x80;
    LPC_IOCON->PIO1_11 = 0x80;
    LPC_IOCON->PIO1_12 = 0x80;
    LPC_IOCON->PIO1_13 = 0x80;
    LPC_IOCON->PIO1_14 = 0x80;
    LPC_IOCON->PIO1_15 = 0x80;

    LPC_IOCON->PIO1_16 = 0x90;
    LPC_IOCON->PIO1_17 = 0x90;
    LPC_IOCON->PIO1_18 = 0x90;
    LPC_IOCON->PIO1_19 = 0x90;
    LPC_IOCON->PIO0_7 = 0x80;
    LPC_IOCON->PIO1_23 = 0x80;
    LPC_IOCON->PIO0_21 = 0x88;
    LPC_IOCON->PIO0_1 = 0x80;

    LPC_GPIO->DIR[0] = 0x00000080;
    LPC_GPIO->PIN[0] = 0x00000080;
    LPC_GPIO->DIR[1] = 0x00800000;
    LPC_GPIO->PIN[1] = 0x00800000;
}

int main(void) {
//    usbdevice.printf("Smoothiepanel Prototype 3\r\n");
//    usbdevice.printf("firmware version: alpha 0\r\n");

    uart.baud(115200);
    uart.format(8, SerialBase::None, 1);
    uart.printf("Smoothiepanel Prototype 3\r\n");
    uart.printf("firmware version: alpha 0\r\n");

    spidevice.format(16, 0);
    spidevice.frequency(1000000);
    spidevice.reply(0x0000); // preload spi slave with null reply

    init_gpio();

    lcd_d.input();
    lcd_rs = 0; // 0 cmd, 1 dat
    lcd_rw = 0; // 0 write, 1 read
    lcd_en = 0;
    lcd_psb = 1; // 0 serial, 1 parallel
    lcd_rst = 0;
    wait(0.01);
    lcd_rst = 1;
    wait(0.01);
    lcd_rst = 0;

    spimaster.format(8,0);
    spimaster.frequency(1000000);
    spi_ssel = 1;
    sd_ssel = 1;

    i2c.frequency(10000);

    while (true) {
        usbdevice_onloop();
        uartdevice_onloop();
        spidevice_onloop();
        nunchuck_onloop();
        encoder_onloop();
    }
}

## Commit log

2013-07-01 Initial commit (Prototype 1)
    [SmoothiePanel.brd, SmoothiePanel.sch]
2014-02-09 Initial commit (Prototype 3)
    Includes hardware and firmware source
    [SmoothiePanel.brd, SmoothiePanel.sch, Smoothiepanel.brd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]
2014-02-09 Added flashing to readme
    [Smoothiepanel.brd, Smoothiepanel.sch]
2014-02-10 Added openmoko usb vid/pid 0x1D50/0x60A0
2014-02-10 Added windows driver for usb serial
2014-02-11 added encoder module
2014-08-15 Initial hardware commit (Prototype 5)
    [Smoothiepanel.brd, Smoothiepanel.sch]

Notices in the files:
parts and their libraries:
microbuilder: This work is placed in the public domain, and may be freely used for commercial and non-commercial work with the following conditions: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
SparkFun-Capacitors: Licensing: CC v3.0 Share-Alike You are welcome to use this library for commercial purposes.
